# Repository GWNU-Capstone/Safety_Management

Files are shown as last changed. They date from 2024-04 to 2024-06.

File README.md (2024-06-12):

# 👷🏻 SMART GATE - Safety_Management
> 공사장 출입시스템을 개발해 근로자의 건강 상태 및 근로 환경을 모니터링 하는 시스템 🔥

<p align="center">
  applogo
  <br><br>
  
  
  
  
</p>

<br>

## 📑 프로젝트 설명
건설 현장에서의 안전 관리 중요성은 매년 점점 증가하고 있습니다.

이러한 문제에 대응하기 위해, 출입 관리와 건강 상태 모니터링을 통합한 시스템을 개발 목표로 선정했습니다.

<br>

## 🕒 개발 기간
* 2024.03.11일 ~

|||
|:-:|:-:|

|||
|:-:|:-:|

<br>

## 👩🏻‍💻🧑🏻‍💻 프로젝트 멤버
|||||||
|:-:|:-:|:-:|:-:|:-:|:-:|
|[@taek2222](https://github.com/taek2222)|[@chaewon9472](https://github.com/chaewon9472)|[@02present](https://github.com/02present)|[@Yunwendy](https://github.com/Yunwendy)|[@fullmoon1219](https://github.com/fullmoon1219)|[@sapang123](https://github.com/sapang123)|
|✔️ PM - Back |✔️ Back |✔️ Hardware |✔️ Hardware |✔️ Front |✔️ Front |

<br>

## 🗂️ API 명세서
### 📕 Backend(Spring Boot)
| 포인트 역할 | Method | URL | 요약 설명 |
|:---:|:---:|:---|---|
| **근로자 일부 정보 요청** | GET | '/user/fingerprint/{사용자 ID}' | 근로자 ID 기반 요청을 통해 일부 정보를 반환한다.|
| **근로자 전체 정보 요청** | GET | '/user/all' | 근로자 전체에 대한 일부 데이터 정보를 반환한다. |
| **근로자 상세 정보 요청** | GET | '/detail/{사용자 ID}' | 근로자에 대한 상세 데이터 정보를 반환한다. |
| **근로자 등록** | POST | '/user/crate' | 새로운 근로자를 데이터베이스에 등록한다. |
| **출근 등록 요청** | POST | '/user/go' | 각종 센서 측정을 마친 후 출근을 등록한다. |
| **근로자 상세정보 수정**  | PATCH  | '/update/{사용자ID}' | 근로자 상세조회 화면으로 근로자 정보를 반환한다. |
| **근로자 정보 삭제** | DELETE  | '/delete/{사용자ID}' | 근로자 정보를 삭제한다. |
| **근로자 출근현황 요청** | GET  | '/today/user-status' | 출근자, 퇴근자, 미출근자 수와 각각의 목록을 반환한다. |
| **근로자 알코올 이상자 정보 요청**  | GET  | '/today/alcohol-abusers' | 알코올 기준수치를 초과한 근로자 수와 그의 목록을 반환한다. |
| **근로자 측정값 평균 요청** | GET  | '/today/data-average' | 근로자들의 측정값(체온, 심박수, 산소포화도) 각각의 평균을 반환한다. |
| **근로자 종합 데이터 요청** | GET  | '/today/user-health-status' | 근로자 상태(정상,주의,심각)에 대한 인원 수와 사용자 각각에 대한 상태 데이터를 반환한다. |
| **전날 평균 근로시간 요청** | GET  | '/yesterday/average-worktime' | 전날 데이터를 기준으로 근로자들의 근로시간의 평균을 반환한다.  |
### 📝 [Backend API 상세 명세서 자세히보기 (클릭)](https://github.com/GWNU-Capstone/Safety_Management/blob/taek2222-patch-1/Back/README.md)
<br>

### 📘 Software 아두이노(Arduino) + 라즈베리파이(Raspberry Pi)
| 포인트 역할 | Method | URL | 요약 설명 |
|:---:|:---:|:---|---|
| **지문 측정결과** | GET | '/fingerprint' | 지문 인식을 통해 사용자 아이디를 반환한다. |
| **지문 등록정보** | GET | '/fingerprint/info'  | 지문 인식기에 등록되어있는 정보를 확인한다. |
| **지문 등록** | GET | '/fingerprint/add/?location=' | 지문을 등록한다. ?location= 뒤에 번호를 입력하면 특정 위치에 등록할 수 있다. </br>없는경우 0번부터 순서대로 입력됨. |
| **지문 제거** | GET | '/fingerprint/rm/?location=' | 지문을 삭제한다. ?location= 뒤에 삭제할 번호를 입력해야 작동한다. |
| **음주 측정결과** | GET | '/drink' | 음주 센서에서의 측정값을 반환한다. |
| **체온 및 심박 측정결과**| GET | '/tempheart' | 체온 및 심박 센서에서의 측정값을 반환한다. |
| **사진 촬영**| GET | '/camera' | 사진을 촬영한 후 해당 사진을 반환한다. |
| **심박센서 켜기**| GET | '/hrstart' | 심박센서를 켠다 (서버 실행시 기본으로 켜짐) |
| **심박센서 끄기**| GET | '/hrstop' | 심박센서를 끈다 (심박센서 오류발생시 대처용)

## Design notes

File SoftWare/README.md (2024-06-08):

## 🗂️ API 상세 정보
### 📘 Software 아두이노(Arduino) + 라즈베리파이(Raspberry Pi)
### 📘(Software) 지문 정보 요청
- **URL**: `/users/fingerprint`
- **Method**: GET
- **성공 응답**:
  - **지문 검색 실패**:
    ```json
    {"fingerprint_results":"Not Found"}
    ```
  - **지문 검색 시간초과**:
    ```json
    {"fingerprint_results":"No Response"}
    ```
  - **지문 검색 성공**:
    ```json
    {"fingerprint_results":0} 
    ```
* * *
### 📘(Software) 지문 추가 요청
- **URL**: `/users/fingerprint/add?location=`
- **Method**: GET
- **성공 응답**:
  - **지문 등록 성공**:
    ```json
    {"fingerprint_addresults":"Stored model at #1"}
    ```
  - **지문 등록 실패**:
    ```json
    {"fingerprint_addresults":"False"}
    ```  
* * *
### 📘(Software) 지문 삭제 요청
- **URL**: `/users/fingerprint/rm?location=`
- **Method**: GET
- **성공 응답**:
  - **지문 삭제 성공**:
    ```json
    {"fingerprint_removeresults":"Template at location 1 deleted successfully."}
    ```
  - **지문 삭제 실패 (location에 아무것도 입력되지 않은 경우)**:
    ```json
    {"fingerprint_removeresults":"location value is none"}
    ```
  - **지문 삭제 실패 (location에 0부터 127 사이의 정수가 입력되지 않은 경우)**:
    ```json
    {"fingerprint_removeresults":"Invalid location. Please provide a location between 0 and 127."}
    ```
* * *
### 📘(Software) 심박, 산소포화도 요청
- **URL**: `/users/fingerprint/tempheart`
- **Method**: GET
- **성공 응답**:
  - **성공**:
    ```json
    {"userHeartRate":120.032,"userSpo2":99.982,"userTemp":37.0}
    ```
* * *
### 📘(Software) 음주 정보 요청
- **URL**: `/users/fingerprint/drink`
- **Method**: GET
- **성공 응답**:
  - **성공**:
    ```json
    {"userdrink":0.01}
    ```

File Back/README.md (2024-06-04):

## 🗂️ API 명세서
### 📕(Back) 근로자 일부 정보 요청
- **URL**: `/users/fingerprint/{사용자 ID}`
- **Method**: GET
- **성공 응답**:
  - **출근 O / 퇴근 X**:
    ```json
    {
      "code": 101,
      "userEnd": "21:43:51" (퇴근 기록 시간)
    }
    ```
  - **출근 O / 퇴근 O**:
    ```json
    {
      "code": 102
    }
    ```
  - **출근 X / 퇴근 X**:
    ```json
    {
      "code": 103,
      "userImage": "1.png" (사진)
      "userNo": 1, (사원 번호)
      "userName": "홍길동" (이름)
    }
      ```
* * *

### 📕(Back) 근로자 전체 정보 요청
- **URL**: `/users/all`
- **Method**: GET
- **성공 응답**:
  - **Content**:
    ```json
    {
      "userNo": 1,
      "userPosition": "관리직", (근로자 관직)
      "userName": "홍길동", 
      "userAge": 25, (나이)
      "userGender": "남성", (성별)
      "userTelNo": "01012345678", (전화번호)
      "userEmail": "abc@naver.com", (이메일)
      "userAddress": "강원특별자치도 원주시" (주소)
    }
    ...
    ```

* * *

### 📕(Back) 근로자 상세 정보 요청
- **URL**: `/detail/{사용자 ID}`
- **Method**: GET
- **성공 응답**:
  - **Content**:
    ```json
    {
      "userNo": 1,
      "userName": "홍길동",
      "userImage": "1.png",
      "userResidentNum": "000000-1234567",
      "userAge": 25,
      "userTelNo": "01012345678",
      "userGender": "남성",
      "userPosition": "관리직",
      "userEmail": "1abc@naver.com",
      "userAddress": "강원특별자치도 원주시",
      "userBank": "우리은행", (은행)
      "userAccount": "1002-123-456789", (계좌 번호)
      "userJoinDate": "2024-03-01", (입사 일자)
      "memo": "메모" (메모)
    }
    ```

* * *

### 📕(Back) 근로자 등록
- **URL**: `/user/crate`
- **Method**: POST
- **전송 데이터**:
  - **Params**
    ```json
    {
        "userNo" : 7, 
        "userPosition" : "사장",
        "userName" : "홍길동", 
        "userAge" : 33,
        "userGender" : "남성",
        "userTelNo" : "01012345678",
        "userEmail" : "1abc@naver.com",
        "userAddress" : "강원도"
    }
    ```  
- **성공 응답**:
  - **Content**:
    ```json
    {
        "userNo" : 7, 
        "userPosition" : "사장",
        "userName" : "홍길동", 
        "userAge" : 33,
        "userGender" : "남성",
        "userTelNo" : "01012345678",
        "userEmail" : "1abc@naver.com",
        "userAddress" : "강원도"
    }
    ```

* * *

### 📕(Back) 출근 등록 요청
- **URL**: `/user/go`
- **Method**: POST
- **전송 데이터**:
  - **Params**
    ```json
    {
      "userNo": 1, (사원 번호)
      "userDrink" : 0.05, (음주 측정)
      "userHeartRate": 69, (심박수)
      "userTemp": 29.8, (체온)
      "userOxygen" : 89 (산소포화도)
    }
    ```  
- **성공 응답**:
  - **Content**:
    ```json
    {
      "userProfile": {
        "userName": "홍길동",
        "userNo": 1
      },
      "date": "2024-04-13", (출근 날짜)
      "userEnd": null, (퇴근 시간)
      "userDrink": 0.05, 
      "userTemp": 29.8,
      "userHeartRate": 69,
      "userOxygen": 89,
      "userDataNo": 14, (데이터 번호)
      "userStart": "18:30:00"
    }
    ```

* * *

### 📕(Back) 사용자 상세정보 수정
- **URL**: `/update/{사용자ID}`
- **Method**: PATCH
- **전송 데이터**:
  - **Params**
    ```json
    {
      "userNo" : 3,
      "userName" : "홍길동",
      "userImage" : "11.png",
      "userResidentNum" : "123456-1234567",
      "userAge" : 60,
      "userTelNo" : "01044444441",
      "userGender" : "남성",
      "userPosition": "사장",
      "userEmail": "1abc@naver.com",
      "userAddress": "강원도",
      "userBank" : "국민은행",
      "userAccount": "123-4567-1234",
      "userJoinDate": "2024-04-28"
      "memo" : "example"
    }
    ```
    
- **성공 응답**:
  - **Content**:
    ```json
    {
      "userNo": 3,
      "userImage": "11.png",
      "userResidentNum": "123456-1234567",
      "userAge": 60,
      "userTelNo": "01044444441",
      "userGender": "남성",
      "userPosition": "사장",
      "userEmail": "1abc@naver.com",
      "userAddress": "강원도",
      "userBank": "국민은행",
      "userAccount": "123-4567-1234",
      "userJoinDate": "2024-04-28",
      "memo": "example",
      "userProfile": {
        "userName": "홍길동",
        "userNo": 3
                    }
    }
    ```

* * *
    
### 📕(Back) 사용자 정보 삭제
- **URL**: `/delete/{사용자ID}`
- **Method**: DELETE
- **응답 상태**:
- 
  성공 시 204 No Content
  
  오류발생 시 500 Internal Server Error 등
* * *

### 📕(Back) 근로자 출근현황 요청
- **URL**: `/today/user-status`
- **Method**: GET
- **성공 응답**:
  - **Content**:
    ```json
    {
          "presentCount": 2,
          "departedCount": 0,
          "yetStartedCount": 4,
    
          "presentUsersList": [
          {
              "userName": "이채원",
              "userNo": 4
          },
          {
              "userName": "박광수",
              "userNo": 3
          }
       ],

          "departedUsersList": [],
  
          "yetStartedUsersList": [
          {
              "userName": "오연택",
              "userNo": 1
          },
          {
              "userName": "김민서",
              "userNo": 2
          },
          {
              "userName": "윤예지",
              "userNo": 5
          },
          {
              "userName": "박현재",
              "userNo": 6
          }
       ]
      
    }
    ```

 * * *

### 📕(Back) 근로자 알코올 이상자 정보 요청
- **URL**: `/today/alcohol-abusers`
- **Method**: GET
- **성공 응답**:
   - **Content**:
    ```json
    {
      "alcoholAbuserCount": 2,
      "alcoholAbusers": [
          {
              "userName": "이채원",
              "userNo": 4
          },
          {
              "userName": "윤예지",
              "userNo": 5
          }
      ]
  }
  ```

* * *

### 📕(Back) 근로자 측정값 평균 요청
- **URL**: `/today/data-average`
- **Method**: GET
- **성공 응답**:
   - **Content**:
    ```json
    {
      "averageOxygen": 95.0,
      "averageHeartRate": 91.3,
      "averageTemp": 37.4
   } 
    ```
    
* * *

### 📕(Back) 근로자 종합 데이터 요청
- **URL**: `/today/user-health-status`
- **Method**: GET
- **성공 응답**:
   - **Content**:
    ```json
    {
      "totalResultCount": {
          "정상": 2,
          "주의": 2,
          "심각": 2
      },
    
      "userStatusList": [
          {
              "userNo": "1",
              "userName": "오연택",
              "totalResult": "정상", 
              "userDrink": "정상",
              "userTemp": "정상",
              "userOxygen": "정상",
              "userHeartRate": "정상"
    
          },
          {
              "userNo": "2",
              "userName": "김민서",
              "totalResult": "주의", 
              "userDrink": "정상",
              "userTemp": "정상",
              "userOxygen": "정상",
              "userHeartRate": "주의"
              
          },
          {
              "userNo": "3",
              "userName": "박광수",
              "totalResult": "심각",
              "userDrink": "정상",
              "userTemp": "심각",
              "userOxygen": "정상",
              "userHeartRate": "정상"
              
          },
          {
              "userNo": "4",
              "userName": "이채원",
              "totalResult": "심각",
              "userDrink": "심각",
              "userTemp": "정상",
              "userOxygen": "정상",
              "userHeartRate": "정상"
              
          },
          {
              "userNo": "5",
              "userName": "윤예지",
              "totalResult": "주의",
              "userDrink": "정상",
              "userTemp": "정상",
              "userOxygen": "정상",
              "userHeartRate": "주의"
              
          },
          {
              "userNo": "6",
              "userName": "박현재",
              "totalResult": "정상",
              "userDrink": "정상",
              "userTemp": "정상",
              "userOxygen": "정상",
              "userHeartRate": "정상"
              
            }
        ]
     }
    ```

 * * *
### 📕(Back) 전날 평균 근로시간 요청
- **URL**: `/yesterday/average-worktime`
- **Method**: GET
- **성공 응답**:
   - **Content**:
    ```json
    {
       "hours": 8,
       "minutes": 36
   } 
    ```

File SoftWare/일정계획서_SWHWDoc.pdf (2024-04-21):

일정계획서_SW,HW,Doc | 1

# 일정계획서_SW,HW,Doc

구분 | 추진일정
1주 | 2주 | 3주 | 4주 | 5주 | 6주 | 7주
역할분담 | O
하드웨어 검색 | O | O | O

프로젝트 제안서
작성
| O

아두이노&라즈베
리파이 공부
| | | O | O | O | O

하드웨어 장비 확
정 및 구매
| | | | O | O

하드웨어 설계 및
구현
| | | | | O | O
하드웨어 연결 | O

아두이노에서 센
서값 불러오기
| | | | | | O

아두이노와 라즈
베리파이 연결

백엔드팀과 db 연
결

완성된 장비 테스
트

보완 및 추가

보고서 작성

최종 완성 및 발표

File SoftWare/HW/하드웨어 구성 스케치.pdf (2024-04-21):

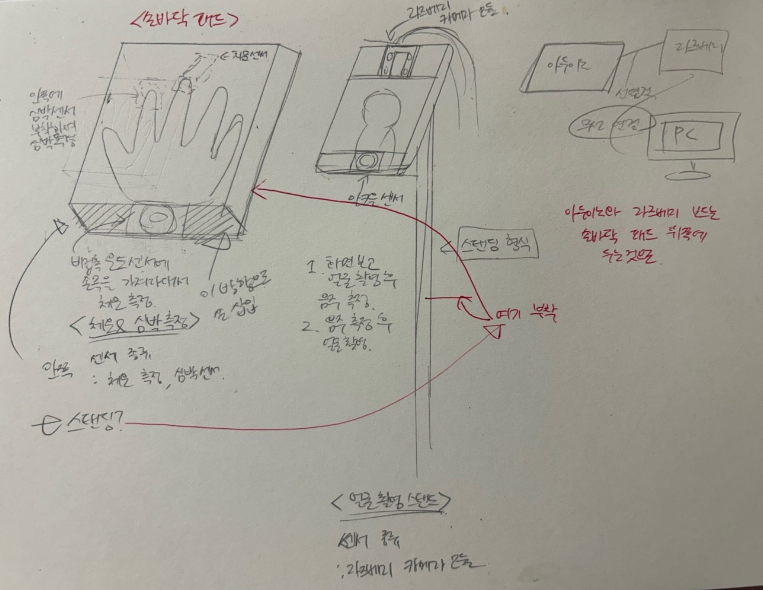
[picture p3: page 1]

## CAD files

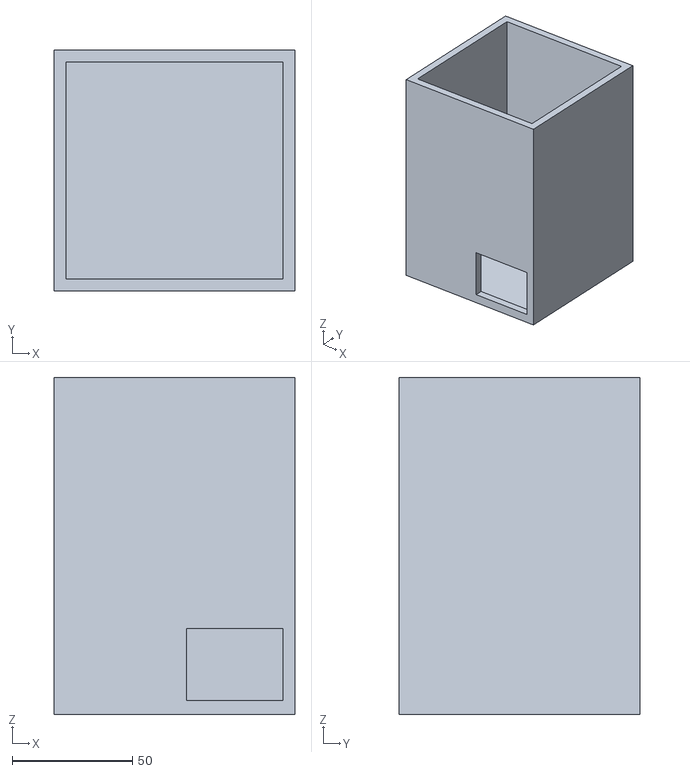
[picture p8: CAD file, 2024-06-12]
SoftWare/HW/stl/box1_하.stl
100.0 x 100.0 x 140.0

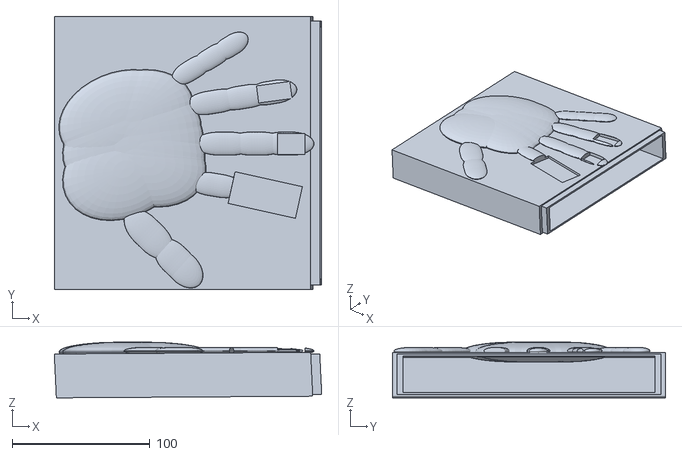
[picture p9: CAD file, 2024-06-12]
SoftWare/HW/stl/modeling.stl
194.0 x 198.0 x 40.4

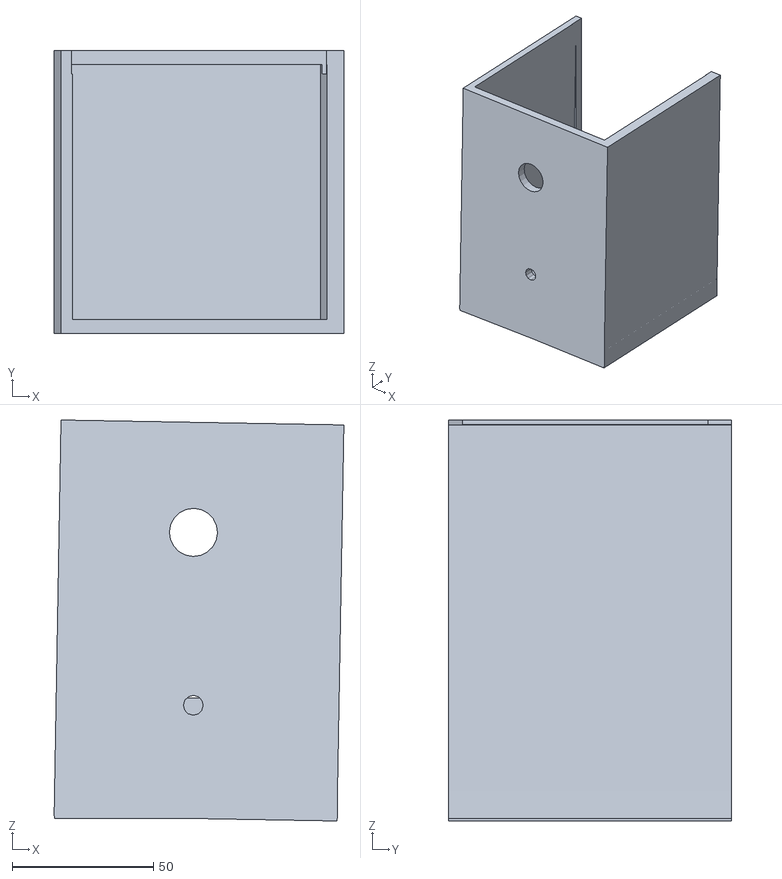
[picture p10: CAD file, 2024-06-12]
SoftWare/HW/stl/box2_상.stl
102.4 x 100.0 x 141.7

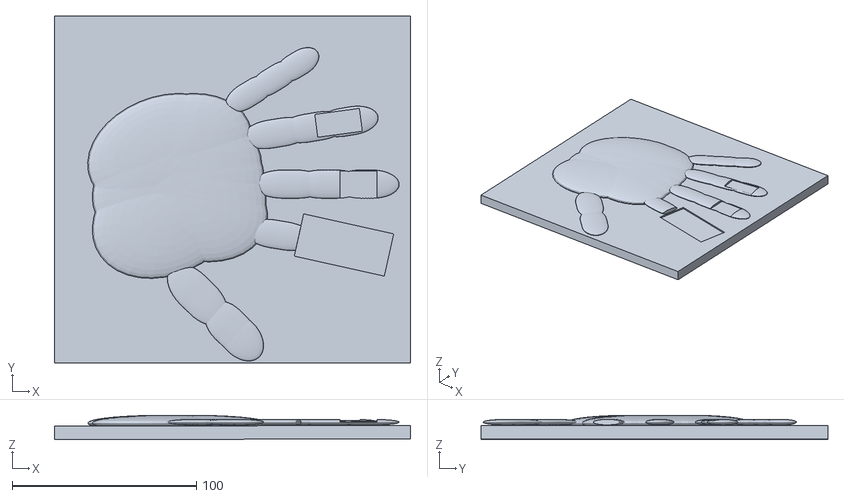
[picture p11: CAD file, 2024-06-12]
SoftWare/HW/stl/modeling_공간없음.stl
193.1 x 188.0 x 13.2

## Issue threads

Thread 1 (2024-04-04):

[P1] 사용자 모니터링 화면 구현 - Backend

taek2222, 2024-04-04:
# ✨Todo✨

# 사용자 모니터링 서버 개발 🔥

## Back
- [x]  Front ID 기반 개인정보 요청 로직 수정
- [x] 모니터링 화면 개인 정보 전송 (이름, 사원번호, 사진)
- [x] 모든 과정 마친 후  [측정 데이터] + 출근 날짜 + 출근 시간 데이터 포함 후 보관 로직 수정
- [x] ERD 점검 후 삭제할 데이터 선별
- [x] 제작된 엔드포인트 정리
- [x] Service 레이어 생성
- [x] 출근 등록 완료 후 SMS 문자 전송

Closed 2024-04-21.

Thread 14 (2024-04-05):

[P1] 사용자 모니터링 화면 구현 - Frontend

taek2222, 2024-04-05:
# ✨Todo✨

# 사용자 모니터링 화면 개발 🔥

## Front
- [x] 모니터링 화면 구성 (이름, 사원번호, 사진, 음주, 심박수, 온도)
- [x] 안내 메시지 & 안내 음성 출력
- [x] 모니터링 화면 디자인
- [x] 지문 센서 ID 반환 요청
- [x] 사용자 ID 기반 서버로 사용자 데이터 요청
- [x] 사용자 인식 후 소프트웨어 요청 2회 알콜 | 심박수, 체온
- [x] 안내 절차 수정
- [x] 모든 측정 후 출근 완료 화면 및 서버로 출근 요청
- [x] 출근 완료 후 다시 1단계 모니터링 전환
- [x] 응답 코드 101 ~ 103 맞는 퇴근, 퇴근 완료 표시 화면

Closed 2024-04-21.

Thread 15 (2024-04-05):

[P1] 사용자 모니터링 화면 구현 - SoftWare

taek2222, 2024-04-05:
# ✨Todo✨

# 사용자 측정 센서 탐구 및 개발 🔥

## SoftWare
- [x] 모니터링 기능 관련 센서 코드 작성
- [x] 센서 반환 값 시리얼 통신으로 라즈베리파이 전달
- [x] 지문 요청 EndPoint 생성
- [x] 알콜 | 체온, 심박수 요청 EndPoint 생성
- [x] 사용자 측정 센서 탐구 및 개발
- [x] 실물 스케치

02present, 2024-04-19:
from flask import Flask
import serial

app = Flask(__name__)
ser = serial.Serial('/dev/cu.usbmodem1101', 9600)  # 아두이노가 연결된 시리얼 포트

#지문 엔드포인트
@app.route('/fingerprint', methods=['GET'])
def get_sensor_data_fp():
    fingerprint_value = 0 #임시값 입니다.
    #ser.write(b'ReadSensor\n')  # 아두이노로 센서값 요청
    #sensor_value = ser.readline().strip().decode()  # 아두이노로부터 센서값 읽기
    return fingerprint_value

#음주 엔드포인트
@app.route('/drink', methods=['GET'])
def get_sensor_data_alc():
    ser.write(b'alc\n')  # 아두이노로 센서값 요청
    alcsensor_value = ser.readline().strip().decode()  # 아두이노로부터 센서값 읽기
    return alcsensor_value

#체온 심박 엔드포인트
@app.route('/tempheart', methods=['GET'])
def get_sensor_data_temp():
    ser.write(b'temp\n')  # 아두이노로 센서값 요청
    tempsensor_value = ser.readline().strip().decode()  # 아두이노로부터 센서값 읽기
    return tempsensor_value

if __name__ == '__main__':
    app.run(host='0.0.0.0', port=5001)

Closed 2024-05-03.

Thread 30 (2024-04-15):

[P1] 사용자 모니터링 화면 구현 -  PM

taek2222, 2024-04-15:
# ✨Todo✨

# 사용자 모니터링 PM 🔥

## PM
- [x] 프론트 및 소프트웨어 연동 주기적 보고 및 피드백
- [x] 소프트웨어 Flask 서버 구현 방향 안내
- [x] 라즈베리파이 및 아두이노 -> 프론트 사진 전송 방안 탐색

taek2222, 2024-04-16:
from flask import Flask, rendertemplate
app = Flask(name)

@app.route("/")
def home():
    return rendertemplate("html파일명.html")

if name=='__main':
    app.run(host='0.0.0.0')

CSHJ0711, 2024-04-16:
capstone@raspberrypi:~/Desktop $ pip install falsk
error: externally-managed-environment

× This environment is externally managed
╰─> To install Python packages system-wide, try apt install
    python3-xyz, where xyz is the package you are trying to
    install.

    If you wish to install a non-Debian-packaged Python package,
    create a virtual environment using python3 -m venv path/to/venv.
    Then use path/to/venv/bin/python and path/to/venv/bin/pip. Make
    sure you have python3-full installed.

    For more information visit http://rptl.io/venv

note: If you believe this is a mistake, please contact your Python installation or OS distribution provider. You can override this, at the risk of breaking your Python installation or OS, by passing --break-system-packages.
hint: See PEP 668 for the detailed specification.

Closed 2024-04-21.

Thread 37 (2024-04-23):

[P2] 회원 관리 페이지 - Front

taek2222, 2024-04-23:
# ✨Todo✨

# 회원 관리 페이지 🔥

## Front
- [x] 모니터링 화면 산소 포화도 추가

- [x] 회원 관리 페이지 ( 메인 )
  - [x] 페이지 디자인
  - [x] 출력 내용 직위(관리직, 계약직, 일용직) | 사원번호 | 이름 | 나이 | 성별 | 전화번호 | 이메일
- [x] 회원 관리 페이지 ( 상세 )
  - [x] 페이지 디자인
  - [x] 직위 ( 관리직, 계약직, 일용직) | 사원번호 | 이름 | 나이 | 성별 | 전화번호 | 이메일 | 주소 | 입사일자 | 은행 | 계좌번호
  - [x] 아래 하단의 List 형식 근무날짜 | 출근 시간 | 퇴근 시간 | 알코올 | 온도 | 심박 | 산소포화도 | 상태(출근, 퇴근) | 비고
  - [x] 화면 표시 데이터 수정 및 삭제 기능.

Closed 2024-05-19.

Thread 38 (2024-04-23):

[P2] 회원 관리 페이지 구현 - Back

taek2222, 2024-04-23:
# ✨Todo✨

# 회원 관리 페이지 구현 🔥

## Back
- [x] 회원 관리 데이터 추가
- [x] 모니터링 산소포화도 데이터 추가 및 POST 요청에도 기록 수정
- [x] 회원 관리에 필요한 데이터 전송
  - [x] 회원 관리(메인) All GET 요청 생성
  - [x] 회원 관리(상세)
    - [x] ID 기반 GET 요청 생성
    - [x] ID 기반 PATCH 요청 생성
    - [x] ID 기반 DELETE 요청 생성

Closed 2024-05-07.

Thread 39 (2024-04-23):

[P1] 사용자 모니터링 화면 구현 (2) - SoftWare

taek2222, 2024-04-23:
# ✨Todo✨

# 사용자 모니터링 화면 구현 (2) 🔥

## SoftWare
- [x] 지문 인식 센서 오작동 없이 구현
- [x] 압력 센서 기반 알코올 측정 개선
- [x] 산소포화도 기반 체온, 심박 측정 개선
- [x] 아두이노 센서 최대한 라즈베리파이로 전환
- [x] 센서 Null 및 쓰레기 값 체크

02present, 2024-04-30:
(0430)
지문인식센서 (USB to TTL) : 라즈베리파이 이식 성공, 엔드포인트 생성 완료
산소 & 심박센서(I2C) : 라즈베리파이 이식 성공, 엔드포인트 생성 완료, 프론트팀과 통신 성공.
체온센서(ADC) : 고장으로 주문, 아날로그 데이터 -> 디지털로 변환 부품 주문.
알코올센서(ADC) : 아날로그 데이터 -> 디지털로 변환 부품 주문.
압력센서(ADC) : 아날로그 데이터 -> 디지털로 변환 부품 주문.
미세먼지센서 : 개발 전.
카메라 : 개발 전.

02present, 2024-05-14:
(0514)
지문인식센서 (USB to TTL) : 라즈베리파이 이식 성공, 엔드포인트 생성 완료
산소 & 심박센서(I2C) : 라즈베리파이 이식 성공, 엔드포인트 생성 완료, 프론트팀과 통신 성공.
체온센서(ADC) : I2C 통신을 이용하여 통신. 센서 불안정으로 모든 센서 세팅 완료시까지 연결 대기중
알코올센서(ADC) : ADC 이용하여 통신 성공. 기존 아날로그 데이터 (0~1024) 에서 0.01 단위로 변경작업 완료.
압력센서(ADC) : ADC 이용하여 통신 성공하였으나, 바람의 무게는 감지하지 못함.
미세먼지센서 : 개발 전.
카메라 : 개발 전.
조도센서 : 구매예정.

Closed 2024-05-20.

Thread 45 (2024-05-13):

[P2] 회원 관리 페이지 (2) - Front

taek2222, 2024-05-13:
# ✨Todo✨

# 회원 관리 페이지 (2) 🔥

## Front
### 회원 관리 (메인)
- [x] 목록 출력 시 사원 번호 순서대로
- [x] 회원 생성 시 전화번호 3칸 분리
- [x] 회원 생성 API 요청 시 전화번호 3칸 합쳐서 전달
- [x] 회원 생성 디자인

### 회원 관리 (상세)
- [x] 데이터 수정 시 사원 번호 고정
- [x] 데이터 수정 시 성별, 직위 선택 방식 변경
- [x] 데이터 목록 비고 삭제
- [x] 메모란 상세 표시 가장 하단으로 수정
- [x] 데이터 표시 (전체, 필터링)

Closed 2024-05-20.

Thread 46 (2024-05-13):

[P2] 회원 관리 페이지 (2) - Back

taek2222, 2024-05-13:
# ✨Todo✨

# 회원 관리 페이지 (2) 🔥

## Back
- [x] 데이터 목록 EndPoint 에러 수정 후 완성
- [x] 데이터 목록 필터링 EndPoint 수정
- [x] ROLLBACK TRANSACTION 기능 추가
- [ ] 코드 최적화

### 추가적 고려 사항
- 통계 표시 구상

Closed 2024-05-20.

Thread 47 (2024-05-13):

[P1] 사용자 모니터링 화면 구현 (3) - SoftWare

taek2222, 2024-05-13:
# ✨Todo✨

# 사용자 모니터링 화면 구현 (3) 🔥

## SoftWare
- [x] 압력 센서 + 알코올 측정 기능 완성
- [x] 알코올 측정된 값 기준치
- [x] 통계에 필요한 온-습도, 조도, 미세먼지 센서 확인
- [x] 실물 모델링 작업

02present, 2024-05-14:
(0514)
지문인식센서 (USB to TTL) : 라즈베리파이 이식 성공, 엔드포인트 생성 완료
산소 & 심박센서(I2C) : 라즈베리파이 이식 성공, 엔드포인트 생성 완료, 프론트팀과 통신 성공.
체온센서(ADC) : I2C 통신을 이용하여 통신. 센서 불안정으로 모든 센서 세팅 완료시까지 연결 대기중
알코올센서(ADC) : ADC 이용하여 통신 성공. 기존 아날로그 데이터 (0~1024) 에서 0.01 단위로 변경작업 완료.
압력센서(ADC) : ADC 이용하여 통신 성공하였으나, 바람의 무게는 감지하지 못함.
미세먼지센서 : 개발 전.
카메라 : 개발 전.
조도센서 : 구매예정.

Closed 2024-05-20.

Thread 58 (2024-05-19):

[FINAL] PROEJCT - Back

taek2222, 2024-05-19:
# ✨Todo✨

# [FINAL] PROEJCT 🔥

## Back
### taek2222
- [x] 온도, 습도, 미세먼지, 조도 값 받는 POST
- [x] 온도, 습도, 미세먼지, 조도 값 전달하는 GET
- [x] 전날 근로자 평균 근로 시간 GET
- [x] AI 기반 공사장 상태 평가 GET
- [x] 문자 mmHg -> bpm

### chaewon9472
- [x] 출근 현황 값 GET
 - [x] 출근, 결근 데이터 상세보기 GET
- [x] 근로자 알코올 이상자 수 GET
 - [x] 알코올 이상자 데이터 상세보기 GET
- [x] 근로자 평균 수치 값 GET
- [x] 근로자 종합 데이터 (정상,주의,심각)  GET
- [x] 근로자 종합데이터 상세보기 GET

### 공통 사항
- [x] ROLLBACK TRANSACTION 기능 추가
- [x] 코드 최적화

Closed 2024-06-07.

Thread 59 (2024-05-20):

[FINAL] PROEJCT - Front

taek2222, 2024-05-20:
# ✨Todo✨

# [FINAL] PROEJCT 🔥

## Front
- [x] 모니터링 문제
  - [x] 소프트웨어와 통신 문제
    - [x] 지문 요청 후 반환 값 기반 작동 (만약, 오류 코드 시 되돌아가게)
  - [x] 하단 짤리는 현상
  - [x] 최종적으로 작동 이상 없는지 확인
- [x] 직원 관리 - 상세 메모 안보이는 현상
- [x] 직원 관리 - 상세 - 수정 직위, 성별 선택형으로 변경
- [x] 데이터 검색 기능 개선 (직원관리, 상세 2개 모두)
- [x] 직원 등록 디자인
- [x] 근로자 평균 <-> 알코올 이상자 위치 변경
- [x] 그래프 1분 단위 최대 10줄
- [x] 출근 현황, 근로자 종합 데이터, 알코올 이상자 ( 상세보기 ) 생성

Closed 2024-06-08.

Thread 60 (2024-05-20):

[FINAL] PROEJCT - Software

taek2222, 2024-05-20:
# ✨Todo✨

# [FINAL] PROEJCT 🔥

## Software
- [x] 모니터링 관련 문제
  - [x] 지문 센서 오류
  - [x] 지문 센서 20초 이상 대기 시 오류 코드 반환
  - [x] 알코올 센서 기준 값 선별 후 무한 대기로 생성
  - [x] 체온 센서 장착
  - [x] 체온, 심박수, 산소 포화도 측정 (하나라도 미측정 시 응답 X)
  - [x] 알코올, 산소포화도 소수점 절삭
- [x] 통계에 필요한 온-습도, 조도, 미세먼지 센서 확인
- [x] 실물 모델링 (우드락, 3D 모델링) 출력
- [x] 센서 정리 후 장착 크기 고려
- [x] 카메라 모듈 장착
- [x] 카메라 스크린샷 촬영 EndPoint 생성

02present, 2024-05-20:
0521
지문센서 오류 -> 짧은 시간 내에 너무 많은 요청으로 인한 오류. 최소한 2~3초 정도의 텀을 두고 요청을 보내야 함. (내부 캐시 저장소의 쓰기 문제로, 정상화까지 꽤나 오랜 시간이 걸림. 프론트에서 너무 연속된 요청을 삼가야 함)
알코올 센서 -> 맨 처음 측정된 값과 10% 범위를 벗어난 상태에서 소숫점 둘째자리까지 5회 같아야 리턴. (1.5초 간격) 조건 만족하지 못할 시 무한루프
심박수, 산소포화도, 체온센서 -> 심박수는 30.0 이상, 산소포화도는 90.0 이상, 체온은 30도에서 45도 사이일 때에만 리턴함. 그 외의 결과값이 나온 경우 무한루프

알코올은 소수점 둘째자리까지, 심박과 산소포화도는 소수점 셋째자리까지 출력됨

02present, 2024-05-21:
0522
카메라 기능 완료

02present, 2024-05-23:
0523
조도센서 연결완료

02present, 2024-05-26:
0526

체온센서 연결 완료

02present, 2024-05-27:
0527

심박센서 오류 (고장으로 추정)

Closed 2024-06-07.

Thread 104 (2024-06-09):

[Refactoring] - 엔티티 수정 Backend

chaewon9472, 2024-06-09:
# ✨Entity 리팩토링✨
## Back
### 공통사항

-  @Notnull 어노테이션, nullable = false 명시
-  fetch type 명시하기 (일대다, 다대다 -> lazy, 다대일, 일대일 -> eager)
- `@Data` `@NoArgsConstructor` `@AllArgsConstructor` 어노테이션 사용법 정리 및 결정
- @Builder 코드 어떻게 쓰이는지 알아보기
- int → Long 변수 전환
- 주석으로 설명 추가하는 법

@taek2222

- [ ] AIFeedback
- [ ] SiteEnvironment

@chaewon9472

- [ ] UserData
- [ ] UserInfo
- [ ] UserProfile

taek2222, 2024-06-09:
👍 확인했습니다!
- 작업 날짜 추가하면 더 좋을 거 같아요!

chaewon9472, 2024-06-09:
넵 본문에 엔티티 수정 기한 적어뒀습니다!

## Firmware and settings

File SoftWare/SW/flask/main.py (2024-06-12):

from flask_cors import CORS
from flask import Flask, request, jsonify, send_file
import serial
from heartrate_monitor import HeartRateMonitor
from smbus2 import SMBus
from mlx90614 import MLX90614
from picamera2 import Picamera2
import time
import sys
from datetime import datetime
import math
import threading
import requests
import json
import as608_combo_lib3 as as608
import adc as adc

arg = 0.01

if len(sys.argv) == 2:
    try:
        arg = float(sys.argv[1])
    except ValueError:
        print("Error: The argument bust be a float.")
        sys.exit(1)
print(f"Argument: {arg}")

app = Flask(__name__)
CORS(app) #Frontend CORS Error. 주석처리하면 프론트에서 에러!

session = as608.connect_serial_session("/dev/ttyUSB0") # 지문인식기 Serial
if session == False:
    session = as608.connect_serial_session("/dev/ttyUSB1") # 지문인식기 Serial
print(session)

#camera = Picamera2()

#camera.configure(camera.create_still_configuration())

ser = serial.Serial('/dev/ttyACM0',9600,timeout=1)

#Heartrate Sensor
hrm = HeartRateMonitor()
hrm.start_sensor()

#tempsensor
bus = SMBus(3)
tempsensor = MLX90614(bus,address=0x5A)

import RPi.GPIO as GPIO
GPIO.setmode(GPIO.BCM)
GPIO.setup(17,GPIO.IN, pull_up_down=GPIO.PUD_UP)
GPIO.setup(27,GPIO.IN, pull_up_down=GPIO.PUD_UP)

#전역변수
g_hr = -1.000
g_spo2 = -1.000
g_temp = -1.0
#status = 0 : 측정전   1 : 심각      2 : 주의      3 : 정상
bpm_status = 0
spo2_status = 0
usertemp_status = 0
re = False

#지문 센서 정보 확인 엔드포인트
@app.route('/fingerprint/info', methods=['GET'])
def get_sensor_info_fp():
    result_info = {}
    result_info['templates_list'] = as608.get_templates_list(session)
    result_info['templates_countes'] = as608.get_templates_count(session)
    return jsonify(result_info)

#지문 검색 엔드포인트
@app.route('/fingerprint', methods=['GET'])
def get_sensor_data_fp():
    global re
    re = True
    usertemp_status = 0
    time.sleep(0.5)
    result_found = {}
    result_found['fingerprint_results'] = as608.search_fingerprint_on_device(session, as608)
    return jsonify(result_found)

#지문 등록 엔드포인트
@app.route('/fingerprint/add/', methods=['GET'])
def fingerprint_add():
    result_add = {}
    location_arg = request.args.get('location')
    location = int(location_arg) if location_arg.strip() != '' else None
    result_add['fingerprint_addresults'] = str(as608.enroll_finger_to_device(session, as608, location))
    return jsonify(result_add)
"""
지문 전체 삭제 엔드포인트
@app.route('/fingerprint/rmall/', methods=['GET'])
def fingerprint_remove_all():
    return as608.delete_all_templates(session)
"""

@app.route('/fingerprint/rm/', methods=['GET'])
def fingerprint_remove():
    result_delete = {}
    location = request.args.get('location')
    result_delete['fingerprint_removeresults'] = str(as608.delete_templates(session,location))
    return jsonify(result_delete)

def get_sensor_data_alc():
    result_drink = {}
    consecutive_count = 0
    required_consecutive_count = 3
    last_valid_value = None
    drink_first_value = adc.get_alcvalue(arg)
    time.sleep(2)
    print(f"first_value : {drink_first_value}")
    while True:
        time.sleep(0.7)
        sensor_value = adc.get_alcvalue(arg)
        drink_value = round(sensor_value,2)
        if drink_value <= 0.00:
            result_drink['userdrink'] = 0.00
            print("return1")
            return jsonify(result_drink)
        if not adc.is_within_range(drink_first_value, sensor_value, 0.3):
            if last_valid_value is None:
                last_valid_value = drink_value
                consecutive_count = 1
            elif drink_value == last_valid_value:
                consecutive_count += 1
                if consecutive_count == required_consecutive_count:
                    print(f"drink return successed: {drink_value}")
                result_drink['userdrink'] = math.floor(drink_value * 100) / 100
                break
            else:
                last_valid_value = drink_value
                consecutive_count = 1
                print(f"Within range: {drink_value} (Consecutive count: {consecutive_count})")
        elif drink_value == 0.00:
            result_drink['userdrink'] = 0.00
            print('return2')
            return jsonify(result_drink)
        else:
            print(f"drink return failed: {drink_value}")
            consecutive_count = 0
            last_valid_value = None
    print("return4")
    return jsonify(result_drink)
    


#음주 엔드포인트
@app.route('/drink', methods=['GET'])
def drinkreturn():
    return get_sensor_data_alc()
    
def read_temperature():
    try:
        data = bus.read_i2c_block_data(0x5A,0x07,3)
        
        temp = (data[1] << 8) | data[0]
        
        temp = temp * 0.02 - 273.15
        return temp
        
    except Exception as e:
        print(f"Error reading from sensor: {e}" )
        return None
        
def get_sensor_data_tempheart():
    hrm.start_sensor()
    #status = 0 : 측정전   1 : 심각      2 : 주의      3 : 정상
    global g_hr, g_spo2, g_temp, bpm_status, spo2_status, usertemp_status, re
    print(f"global value: {g_hr} {g_spo2} {g_temp} {bpm_status} {spo2_status} {usertemp_status}")
    while True:
        #hrm.start_sensor()
        if re == True:
            g_hr = -1.000
            g_spo2 = -1.000
            g_temp = -1.0
            bpm_status = 0
            spo2_status = 0
            usertemp_status = 0
            time.sleep(0.3)
            re = False
        time.sleep(0.5)
        bpm = hrm.bpm
        spo2 = hrm.spo2
        usertemp = read_temperature()
        
        #bpm
        if g_hr == -1.000 and bpm > 30.000: #측정전
            g_hr = bpm
            print(f"global value: {g_hr} {g_spo2} {g_temp} {bpm_status} {spo2_status} {usertemp_status}")
        if (30 < bpm < 50 or bpm > 120) and bpm_status <= 1: #심각
            g_hr = bpm
            bpm_status = 1
            print(f"global value: {g_hr} {g_spo2} {g_temp} {bpm_status} {spo2_status} {usertemp_status}")
        if (50 <= bpm <= 59 or 101 <= bpm <= 120) and bpm_status < 2 : # 주의
            g_hr = bpm
            bpm_status = 2
            print(f"global value: {g_hr} {g_spo2} {g_temp} {bpm_status} {spo2_status} {usertemp_status}")
        if 60 <= bpm <= 100 and bpm_status <= 3 : #정상
            g_hr = bpm
            bpm_status = 3
            print(f"global value: {g_hr} {g_spo2} {g_temp} {bpm_status} {spo2_status} {usertemp_status}")
            
        #spo2
        if g_spo2 == -1.000 and spo2 > 85.000: #측정전
            g_spo2 = spo2
            print(f"global value: {g_hr} {g_spo2} {g_temp} {bpm_status} {spo2_status} {usertemp_status}")
        if 85 < spo2 <= 90 and spo2_status <= 1: #심각
            g_spo2 = spo2
            spo2_status = 1
            print("changed spo2 1")
            print(f"global value: {g_hr} {g_spo2} {g_temp} {bpm_status} {spo2_status} {usertemp_status}")
        if 90 < spo2 < 95 and spo2_status < 2 : # 주의
            g_spo2 = spo2
            spo2_status = 2
            print("changed spo2 2")
            print(f"global value: {g_hr} {g_spo2} {g_temp} {bpm_status} {spo2_status} {usertemp_status}")
        if spo2 >= 95.000 and spo2_status <= 3 : #정상
            g_spo2 = spo2
            spo2_status = 3
            print("changed spo2 3")
            print(f"global value: {g_hr} {g_spo2} {g_temp} {bpm_status} {spo2_status} {usertemp_status}")

        #temp
        if g_temp == -1.0 and usertemp > 20.0 and usertemp < 50: #측정전
            g_temp = usertemp
            print(f"global value: {g_hr} {g_spo2} {g_temp} {bpm_status} {spo2_status} {usertemp_status}")
        if 35.0 <= usertemp <= 38.1 and usertemp_status < 1:#심각
            g_temp = usertemp
            usertemp_status = 1
            print("changed temp 1")
            print(f"global value: {g_hr} {g_spo2} {g_temp} {bpm_status} {spo2_status} {usertemp_status}")
        if 37.3 <= usertemp <= 38.0 and usertemp_status < 2:# 주의
            g_temp = usertemp
            usertemp_status = 2
            print("changed temp 2")
            print(f"global value: {g_hr} {g_spo2} {g_temp} {bpm_status} {spo2_status} {usertemp_status}")
        if 35.1 <= usertemp <= 37.2 and usertemp_status <= 3 : #정상
            g_temp = usertemp
            usertemp_status = 3
            print("changed temp 3")
            print(f"global value: {g_hr} {g_spo2} {g_temp} {bpm_status} {spo2_status} {usertemp_status}")
    return 0 
    
threading.Thread(target=get_sensor_data_tempheart, daemon=True).start()
#체온 심박 엔드포인트
@app.route('/tempheart', methods=['GET'])
def tempheart_return():
    global g_hr, g_spo2, g_temp, bpm_status, spo2_status, usertemp_status
    
    while True:
        if bpm_status >= 1 and spo2_status >= 1: #and usertemp_status >= 1:
                result_tempheart = {}
                result_tempheart['userHeartRate'] = g_hr
                result_tempheart['userSpo2'] = round(g_spo2,3)
                result_tempheart['userTemp'] = 36.5#round(g_temp,1)
                return jsonify(result_tempheart)

@app.route('/hrstart', methods=['GET'])
def startsensor():
    hrm.start_sensor()
    return "OK"

@app.route('/hrstop', methods=['GET'])
def stopsensor():
    hrm.stop_sensor()
    return "OK"
    
@app.route('/camera', methods=['GET'])
def take_a_picture():
    camera.start()
    current_time = datetime.now()
    timestamp_str = current_time.strftime("%Y%m%d_%H%M%S")
    file_name = f"/home/capstone/Desktop/camera/{timestamp_str}.jpg"
    camera.capture_file(file_name)
    print(f"Image captured as {file_name}")
    camera.stop
    return send_file(file_name,mimetype='image/jpeg')
    
    
#H2 Server
H2_SERVER_URL = "http://3.38.71.65/data"

def ardu_sensor_data():
    while True:
        try:
            time.sleep(5)
            if ser.in_waiting > 0:
                line = ser.readline().decode('utf-8').rstrip()
                print(line)
                p_values = line.split()
                
                # p_values ?? ??
                if len(p_values) < 11:  # ??? ??? ?? 10 ???? ??
                    print("Error: Not enough data in line")
                    continue  # ??? ???? ??? ?? ???? ???

                postdata = {
                    #'PM1.0' : p_values[1],
                    #'PM2.5' : p_values[3],
                    'fineDust' : p_values[6],
                    'temperature' : p_values[8],
                    'humidity' : p_values[10],
                    'sunshine' : adc.get_bright_sensor()
                }
                print(postdata)
                
                try:
                    response = requests.post(H2_SERVER_URL, data=json.dumps(postdata), headers={'Content-Type': 'application/json'})
                    if response.status_code == 200 or response.status_code == 204:
                        print('Data Sent')
                        return 0
                    else:
                        print(f'Server error: {response.status_code}')
                except Exception as e:
                    print(f'Request failed: {e}')
        
        except Exception as e:
            print(f'Error occurred: {e}')
            time.sleep(5) 
def post_sensor_data():
    while True:
        time.sleep(30)
        ardu_sensor_data()
        
threading.Thread(target=post_sensor_data, daemon=True).start()
if __name__ == '__main__':
    app.run(host='0.0.0.0', port=5000)

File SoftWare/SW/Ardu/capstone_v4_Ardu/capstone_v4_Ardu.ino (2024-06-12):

#include <pm2008_i2c.h>
#include <DHT11.h>

PM2008_I2C pm2008_i2c;
DHT11 dht11(2);

void setup() {
#ifdef PM2008N
  // wait for PM2008N to be changed to I2C mode
  delay(10000);
#endif
  pm2008_i2c.begin();
  Serial.begin(9600);
  pm2008_i2c.command();
  delay(1000);
}

void loop() {
  uint8_t ret = pm2008_i2c.read();
  if (ret == 0) {
    String data = "PM 1.0: " + String(pm2008_i2c.pm1p0_tsi) + " PM2.5: " + String(pm2008_i2c.pm2p5_tsi) + " PM10: " + String(pm2008_i2c.pm10_tsi);
    
    int temperature = 0;
    int humidity = 0;

    // Attempt to read the temperature and humidity values from the DHT11 sensor.
    int result = dht11.readTemperatureHumidity(temperature, humidity);
    // Check the results of the readings.
    // If the reading is successful, append the temperature and humidity values to the data string.
    // If there are errors, append the appropriate error messages.
    if (result == 0) {
        data += " Temperature: " + String(temperature) + " Humidity: " + String(humidity);
    } else {
        data += " Error: " + String(DHT11::getErrorString(result));
    }

    // Send the combined data string
    Serial.println(data);
  }
  delay(1000);
}

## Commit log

2024-04-05 [Oh] 오류 수정
2024-04-05 [Oh] CORS 설정
2024-04-05 오류 조금 수정 측정한 값이 표시되도록 수정
2024-04-05 [Lee] 알코올, 체온/심박수
2024-04-05 [Lee] idea 삭제, 앤드포인트 /변경, 알코올, 체온/심박수
2024-04-05 [Lee] idea 삭제
2024-04-05 [Lee] 외부 idea 삭제
2024-04-05 파일 정리
2024-04-05 [Lee] 앤드포인트 수정
2024-04-06 안내 순서 변경 및 지문 인식 후 개인정보 표시
2024-04-06 파일 종합
    Resolved #2
2024-04-07 [Oh] 주석 삭제 및 정리
2024-04-07 [Oh] 사용자 (사원번호, 이름, 이미지) API 생성
2024-04-07 [Oh] entity, DTO 대소문자 수정
2024-04-07 [Oh] Date 엔티티 추가, POST 기본 요청 생성
2024-04-07 백엔드 엔드포인토 3개 연결해서 모니터링 화면 기능 구현
2024-04-09 [Lee] 체온.심박수 컨트롤러 -> 알코올 컨트롤러에 동시작성 및 컨트롤러명 변경
2024-04-11 [Oh] webflux 의존성 추가
2024-04-11 [Oh] 리팩토링 및 이름 변경
2024-04-11 [Oh] WebClient 활용한 소프트웨어 요청 로직 변경
2024-04-11 [Oh] 오류 해결 방안 주석 내용
2024-04-12 [Oh] 이름 변경 및 데이터 수정
2024-04-12 [Oh] 출근 메소드 구현 완료
2024-04-12 [Oh] 퇴근 기능 구현 60% 완료
2024-04-12 [Oh] 퇴근 기능 완료
2024-04-12 [Lee] 알코올 요청 (오류), 체온 심박수 요청
2024-04-14 아두이노
2024-04-14 Create 아두이노, 라즈 연결.txt
2024-04-14 [Oh] 바로 리턴 방식으로 변환
2024-04-14 엔드 포인트 3개 연결, post연결은 아직
2024-04-14 HD 스케치
    Resolved #15
2024-04-15 안내단계 수정
2024-04-15 아두이노, 라즈베리파이 코드 변경
2024-04-16 출근 절차 종료 후 맨 처음으로 돌아가는 기능
2024-04-18 [Oh] 데이터 점검 후 필요 없는 부분 삭제
2024-04-18 [Oh] 로직 변경으로 인한 엔드포인트 삭제
2024-04-18 [Oh] 로직 변경 WebClientConfig 주석
2024-04-18 [Oh] 주석 설명 추가
2024-04-18 [Oh] DTO 정리 및 추가
2024-04-18 [Oh] Service 레이어 추가 및 로직 변경
2024-04-18 [Oh] .gitignore 항목 추가
2024-04-18 code값에 따른 안내상황변경 및 멤버관리 페이지 데미데이터 생성
2024-04-18 측정 표기 변경
2024-04-18 안내 절차 시간 수정
2024-04-19 [Lee] 출근기록(+전송받은 데이터) 저장
2024-04-19 [Oh] 추가 의존성, 데이터 수정
2024-04-19 [Lee] userStart 데이터 HH:mm:ss 포맷
2024-04-19 안내 단계 추가 신설
2024-04-19 [Oh] 출퇴근 문자 전송 기능 추가
2024-04-19 api주소 변경과 20초뒤 맨 처음 화면 이동, 일부 안내 절차 자동화
2024-04-20 모니터링 화면 수정
2024-04-23 안내 정보 수정
2024-04-24 [Lee] 엔티티 추가, sql 데이터 추가
2024-04-24 [Lee] 산소포화도 post 요청 추가, Info DTO 데이터 추가
2024-04-27 [Lee] sql -> 주민등록번호 데이터 추가(USER_RESIDENT_NUM), 작업날짜 데이터값 변경
2024-04-27 [Lee] 주민등록번호 엔티티 추가
2024-04-27 [Lee] InfoDTO에 주민등록번호, 이름 추가
2024-04-27 [Lee] 사원정보(상세화면) userNo로 조회,삭제, (수정기능은 해결 중)
2024-04-27 [Lee] 사원정보(상세화면) 수정기능
2024-05-03 member에 사원 등록 추가
2024-05-03 [Oh] 사용하지 않는 웹 요청 Config 삭제
2024-05-03 [Oh] 확인
2024-05-03 [Oh] 유저 전체 조회 엔드포인트 생성
2024-05-04 직원 등록과 직원 삭제 버튼 추가와 기능 추가(api연결은 아직)
2024-05-06 직원 관리, 상세 페이지의 조회 기능과 삭제기능(삭제는 아직 미흡)
2024-05-06 상세 정보 데이터 변경 기능(api만 추가)
2024-05-07 [Oh] CORS DELETE 수정
2024-05-07 [Oh] 유지 보수 강화
2024-05-07 수정 기능 오류 해결
2024-05-07 직원 등록 모달창 기능 변경
2024-05-07 모달창에서 사원번호 추가
2024-05-08 [Oh] 이너클래스 형태로 변경
2024-05-08 [Oh] 직원 Create 생성
2024-05-09 [Oh] 직원 Create 오류 수정
2024-05-09 [Oh] 가입 날짜 추가
2024-05-09 [Oh] 유지보수 강화
2024-05-09 [Oh] 가입 오류 수정
2024-05-09 [Oh] 엔드포인트 및 필드 주석 추가, 데이터 변경
2024-05-09 [Oh] 데이터 수정
2024-05-09 [Oh] 변경된 Entity SQL 변경
2024-05-09 [Lee] 사원정보 상세조회 - null 값 해결
2024-05-09 [Lee] 사원삭제 오류해결 (테이블 참조관계)
2024-05-09 [Lee] 사원삭제 안됨
2024-05-09 [Lee] 사원삭제 미해결
2024-05-09 [Oh] Delete 오류 수정
2024-05-10 직원 등록 기능 구현(지문 번호만 하면 완료)
2024-05-11 직원 상세 정보란 완성
2024-05-11 [Oh] 데이터 생성 부분 설정 중
2024-05-13 버그 일부분 수정
2024-05-15 [Oh] 데이터 목록 표시 오류 수정
2024-05-15 [Oh] 유지 보수를 위해 반환 메서드 추가
2024-05-15 [Oh] 전화번호 '-' 추가 메시지 이상 없음
2024-05-15 [Oh] 필터링 엔드포인트 보류
2024-05-15 상세 정보 오른쪽 기능 구현 완료
2024-05-16 [Lee] 사원정보 삭제 - cascade 적용
2024-05-16 상세에서의 사원번호 편집 불가 및 관리페이지에서의 언제나 오름차순정렬
2024-05-17 전화번호 나누기와 상세에서의 비고란 삭제
2024-05-20 더미데이터 삭제
2024-05-20 [Lee] 트랜잭션, 캐시
2024-05-20 [Lee] 캐시 삭제
2024-05-20 직원 데이터 수정시 선택상자 옵션 추가 및 데이터 검색 기능 강화
2024-05-20 이미지 출력 오류 수정
2024-05-21 post요청에 산소포화도 추가
2024-05-21 아두이노 사용 및 flask 코드 변경
2024-05-21 readme 수정
2024-05-21 [SW] Readme API 상세정보 수정
2024-05-21 [SW]카메라모듈 연결 및 코드반영
2024-05-22 출근 완료 후 지문 인식 진행 안되는 버그 해결
2024-05-23 [HW] 3D Model 파일 업로드 (stl)
    [modeling.stl, modeling_공간없음.stl]
2024-05-23 [Lee] 삭제 - 기존방식으로 변경
2024-05-23 [Lee] 앤드포인트 (today 출근현황, 알코올 이상자, 측정값 평균)
2024-05-23 모니터링 완성
2024-05-23 통계 엔드포인트 3개 연결
2024-05-26 [Lee] 앤드포인트 (종합데이터, 전날 평균근로시간)
2024-05-26 프론트 오류사항 수정
2024-05-26 [SW] 조도센서 및 체온센서 연결 및 추가(v7)
2024-05-26 통계 페이지 상세 정보 표시와 기능 2개 더 구현
2024-05-27 [Lee] 알코올이상자 0.03 해결 ,출근등록 문자 주석해제
2024-05-27 [SW] 알코올센서 기본값 매개변수 설정 및 시간단축 (v8)
2024-05-28 통계페이지 출근, 퇴근, 미출근으로 세부적인 분할
2024-05-28 어감 변경
2024-05-28 [HW] 3D Model 파일 업로드_카메라&알코올 박스(stl)
    [box1_하.stl, box2_상.stl]
2024-05-28 [Lee] 종합상태 경곗값 수정완료
2024-05-30 통계 페이지 modal 사이즈 수정 및 상세정보 링크
2024-05-31 엔드 변경사항 수정
2024-06-01 [Oh] CI/CD 파이프라인 구축을 위한 설정
2024-06-01 [Oh] 줄내림 수정
2024-06-01 [Oh] 오타 수정
2024-06-01 api빼기
2024-06-01 [Oh] 공사장 환경 데이터 테이블 및 레이어 생성
2024-06-01 [Oh] 엔터 정리
2024-06-01 [Oh] 데이터 저장, 반환 컨트롤러 생성
2024-06-01 [Oh] 문자 산소포화도 추가 및 단위 수정
2024-06-02 통계 그래프 데이터 연동 완료 버그 수정 미완료
2024-06-02 [Oh] AI 기능 config 설정
2024-06-02 [Oh] AI 내용 생성 및 반환 서비스
2024-06-02 [Oh] AI 관련 DB, DTO 등 레이어 정의
2024-06-02 버그 수정 및 AI 추가와 스타일 변경 필요
2024-06-02 [Oh] AI 기능 개편 완료
2024-06-02 [Lee] 정상 체온 범위 36.1 -> 35.1로 수정
2024-06-02 AI재설정 버튼 기능 추가 및 메모 업로드 버그 수정과 직원 등록 모달창에서 사원번호 입력되는 현상 수정
2024-06-02 [Lee] 알코올 이상자 - 오늘 날짜 코드 추가
2024-06-02 통계페이지에서 데이터 1분마다 재요청(AI데이터 제외)
2024-06-03 v8_심박, 체온 로직변경
2024-06-03 [Lee] 데이터 넣기
2024-06-03 [Lee] userNo 1번인 사용자- 임시데이터 15개 생성
2024-06-03 [Lee] 코드 취소, db 하드코딩
2024-06-04 v9_flask directory 정리
2024-06-04 [test] 영상업로드
2024-06-04 Revert "v9_flask directory 정리"
    This reverts commit ea8beb2538ee52d3731caea63211cb27746d6735.
    [alcstd.py, camtest.py]
2024-06-05 [SW]_캡스톤 대회ver_v10
